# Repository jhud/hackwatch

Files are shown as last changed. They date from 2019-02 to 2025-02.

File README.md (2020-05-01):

# hackwatch
Want to run your Arduino code anywhere, any time? How about running a webserver from your wrist? This is a smartwatch running on the ESP32 + Arduino + 0.96' OLED (color or monochrome). Designed to run on cheap boards that have inbuilt LiPo battery circuitry and an OLED screen. It makes for quite a chunky watch, but the "always on" glow looks very cool, and a 500mAH battery currently lasts 10+ hours without any optimisation. The whole prototype was built for $12.

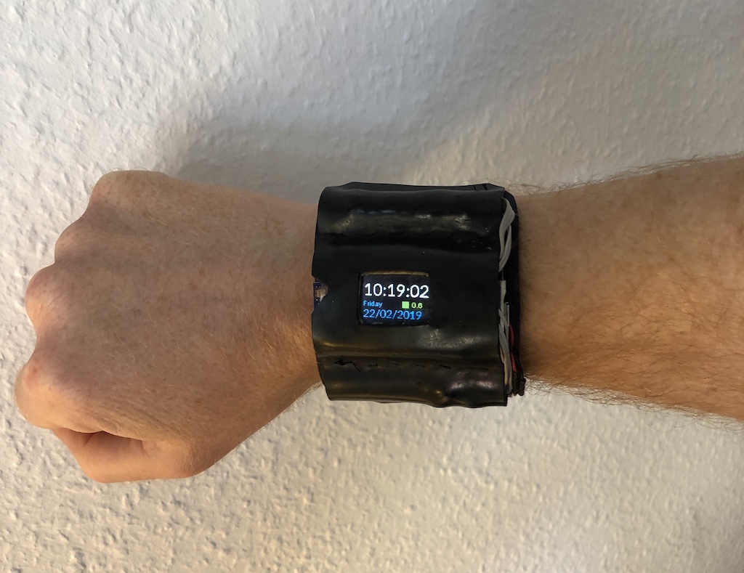
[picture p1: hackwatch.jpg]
Picture of hackwatch prototype Hackwatch prototype


Currently, the code uses your WiFi to sync with an NTP server, then show the time and date. I'll improve this project as I need features and find time.

The "flash" button on the GPIO0 of the development board is repurposed as a function button for the watch.

## Features
 - Flashlight, Stopwatch, Timer, Wifi Scan, UV Sensor with daily exposure graph
 - BLE connection with message notifications
 - Hardcoded calendar functionality, which will remind you when you need to catch buses, etc.
 - Screen off button, goes into sleep mode
 - Switch between color or B&W display on the application level, via a high-level UI interface.

# Setup

## Installation

Install the following dependencies:
 - Time (from Arduino library manager)
 - ```git clone https://github.com/mgo-tec/ESP32_SSD1331``` (for the color SSD1331 display)
 - ```git clone https://github.com/Smartphone-Companions/ESP32NotificationsLib.git``` (for the Bluetooth LE notifications)

You need to create a file called "secrets.h" which has your WiFi SSID and password:

const char ssid[] = "my access point";  //  your network SSID (name)
const char pass[] = "MyPassword12345";       // your network password

If you have an SSD1306 monochrome display, remove the #define COLOR_SCREEN. If you have an SSD1331 color display, set that define. Make sure you have the correct pins set in layout.cpp.

### OSX Troubleshooting

 - On OSX Catalina you might have trouble getting the "TTGO ESP32 OLED" board recognised by Arduino. If so, try installing the driver for the USB chip. https://www.silabs.com/products/development-tools/software/usb-to-uart-bridge-vcp-drivers

# Fabrication
The SVG file can be printed out, and the pieces cut from 1.5mm rubber. For attaching rubber, here are the methods tried (1 star fail, 5 star excellent):
 - Stitching with nylon thread *****
 - Double-sided tape ***
 - Vulcanising rubber cement **
 - Electrical tape **
 - Hot glue *
 The best method was to stick pieces with double-sided tape, and then stitch any load-bearing joins.

# Major tasks yet to do:
- Big refactor of messy prototype code
- Reduce power consumption (i.e. deep sleep when not changing display)
- Piezo chime or vibrate

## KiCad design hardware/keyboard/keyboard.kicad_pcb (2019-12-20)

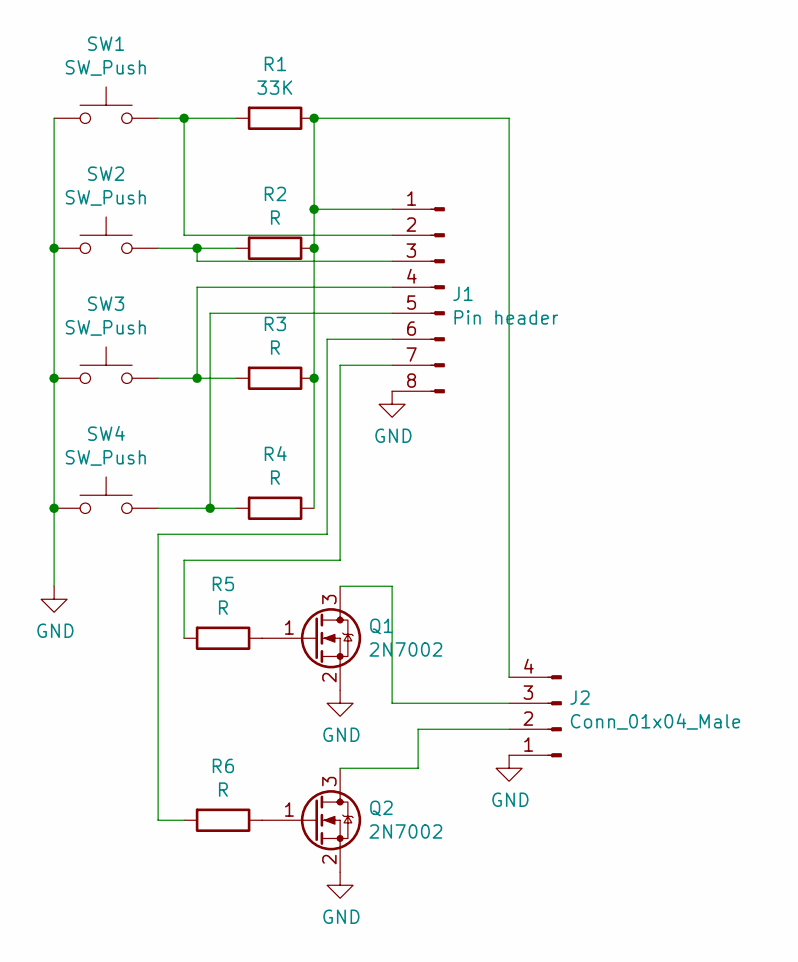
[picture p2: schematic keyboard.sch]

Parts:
J1: Pin header; PinHeader_2x04_P2.54mm_Vertical
J2: Conn_01x04_Male; PinHeader_1x04_P2.54mm_Vertical
Q1, Q2: 2N7002; SOT-23
R1: 33K; R_1206_3216Metric_Pad1.42x1.75mm_HandSolder
R2, R3, R4, R5, R6: R; R_1206_3216Metric_Pad1.42x1.75mm_HandSolder
SW1, SW2, SW3, SW4: SW_Push; SW_SPST_TL3342

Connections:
GND: J1.8, J2.1, Q1.2 (S), Q2.2 (S), SW1.1, SW2.1, SW3.1, SW4.1
unnamed: J1.1, J2.4, R1.1, R2.1, R3.1, R4.1
unnamed: J1.2, R1.2, SW1.2
unnamed: J1.3, R2.2, SW2.2
unnamed: J1.4, R3.2, SW3.2
unnamed: J1.5, R4.2, SW4.2
unnamed: J1.6, R6.2
unnamed: J1.7, R5.2
unnamed: J2.2, Q2.3 (D)
unnamed: J2.3, Q1.3 (D)
unnamed: Q1.1 (G), R5.1
unnamed: Q2.1 (G), R6.1

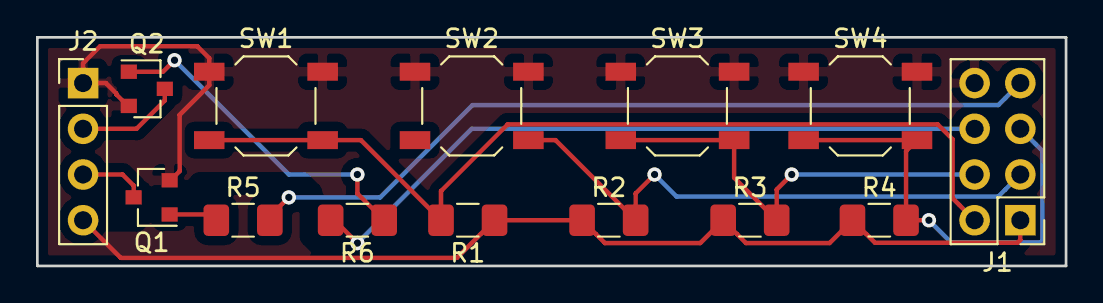
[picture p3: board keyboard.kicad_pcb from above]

Board: 2 copper layers, 57.1 x 12.7 mm, 14 parts (0 on the bottom side), 12 nets.

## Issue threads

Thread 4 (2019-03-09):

Hardware: designs for new keyboard boards

jhud, 2019-03-09:
The keyboards are probably the most clunky hardware part at the moment, and are just made out of through-hole veroboard. Do a proper kicad design. Also could add a space for LED/peripheral/buzzer/vibrator and mosfet.

jhud, 2019-12-20:
Done. Added the kicad files to the repo.

Closed 2019-12-20.

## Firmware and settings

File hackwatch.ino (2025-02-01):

// Smartwatch based on the ESP32 + SSD1306 OLED
// (c)2017 James Hudson, released under the GPL-3.0 license

// NTP based on https://www.arduino.cc/en/Tutorial/UdpNTPClient

// 55mA draw just showing time, changing every second

// Note on ESP32 sleep modes: the deep and light sleeps both work fine with the RTC,
// but on the "TTGO ESP32 OLED" board, the OLED screen blanks itself on sleep because of the reset pin
// configuration. This makes it not so useful for a watch, discounting any hardware mods to
// the board. So GPIO0 is used as an on/off switch.

 
#include <TimeLib.h> 
#include <WiFi.h>
#include <WiFiManager.h> // https://github.com/tzapu/WiFiManager

#include <WiFiUdp.h>

#include "util.h"
#include "states.h"
#include "layout.h"
#include "fonts.h"
#include "web.h"

#include "esp32notifications.h"

#include <esp_adc/adc_oneshot.h>

#define uS_TO_S_FACTOR 1000000  /* Conversion factor for micro seconds to seconds */

#define UV_SENSOR_ENABLE_GPIO 22

inline float mWcm2ToUVI(float mWcm2) { return mWcm2*3; }

static unsigned char uviBuffer[10*60*12];
static int bufferPos;

// NTP Servers:
IPAddress timeServer(216,239,35,8); // time.google.com

const int timeZone = 2; // Berlin winter is 1. Summer is 2

WiFiUDP Udp;


BLENotifications notifications;

static const int MENU_TIME_WIDTH = 30;
static const int STATUS_BAR_HEIGHT = 10;
static const int TIME_Y_POS = STATUS_BAR_HEIGHT; 
static const int timeHeight = 28;
static const int appointmentHeight = 28;
static const int APPOINTMENT_Y_POS = TIME_Y_POS+timeHeight-2;

unsigned long startTime = 0; 
time_t timer = 0;
int lastDay = -1;
int lastMinute = -1;

typedef struct CalendarEvent {
  char name[13];
  char day;
  short int minute;
  short int countdownMinutes;
};

// Sunday = 1
// Saturday = 7
CalendarEvent calendarEvents[] PROGMEM = {
  {"H'str U8", 1, 11*50, 20},
 /* {"Train OK", 3, 10*60, 30},
  {"Train OK", 4, 10*60, 30},
  {"Train OK", 5, 10*60, 30},*/
  {"H'str 277", 5, 20*60 + 5, 30},
};



int buttonPins[] = {32, 25, 26, 27, 35};
uint32_t inputMap;

State state = StateTime;

#define INTERUPT_PIN 0
void onboardButtonPressed() {

        detachInterrupt(INTERUPT_PIN);
        pinMode(INTERUPT_PIN, INPUT);
        Layout::enableDisplay(false);
  esp_sleep_enable_ext0_wakeup(GPIO_NUM_0,0);
    esp_deep_sleep_start();
}

void inputPressed0() { inputMap |=  1; }

void inputPressed1() { inputMap |=  2; }

void inputPressed2() { inputMap |=  4; }

void inputPressed3() { inputMap |=  8; }

void inputPressed4() { inputMap |=  16; }

bool isTimeSet() {
    time_t got_time = now();
 return (got_time > 1000);
}

const char btLogo[] PROGMEM = {0b1000100,0, 0b101000, 0, 0b11111111, 1,0b10101010,0,0b1000100,0};

void onBLEStateChanged(BLENotifications::State state) {
  uint16_t color = BLUE;
  switch (state) {
    case BLENotifications::StateConnected: color = GREEN; break;
    case BLENotifications::StateDisconnected:
      color = DARK_GRAY;

      /* We need to startAdvertising on disconnection, otherwise the ESP 32 will now be invisible.
      IMO it would make sense to put this in the library to happen automatically, but some people in the Espressif forums
      were requesting that they would like manual control over re-advertising.*/
      notifications.startAdvertising(); 
      
      break;
  }

  Layout::drawSprite1Bit(60, 1, 5, 9, btLogo, sizeof(btLogo), color);
}


// A notification arrived from the mobile device, ie a social media notification or incoming call.
void onNotificationArrived(const ArduinoNotification * notification, const Notification * rawNotification) {
    int textHeight = 11;

    String body(notification->message);
    //body.remove(20);

    Layout::drawStringInto(0, DISPLAY_HEIGHT-textHeight*2-2, DISPLAY_WIDTH, textHeight, notification->title, AlignLeft, LIGHT_BLUE);
    Layout::drawStringInto(0, DISPLAY_HEIGHT-textHeight-2, DISPLAY_WIDTH, textHeight, body, AlignLeft, LIGHT_BLUE);
}


void setup() 
{
  Serial.begin(115200);

  pinMode(UV_SENSOR_ENABLE_GPIO,OUTPUT);

  pinMode(34, INPUT);

  pinMode(16,OUTPUT);
  digitalWrite(16, LOW);    // set GPIO16 low to reset OLED
  delay(50); 
  digitalWrite(16, HIGH); // while OLED is running, must set GPIO16 in high

  pinMode(0, INPUT); // Let us use flash button on dev board as a function button

  for (int i=0; i<NUM_OF(buttonPins); i++) {
    pinMode(buttonPins[i], INPUT_PULLUP);  
  }

  Layout::init(false); // left handed

  memset(uviBuffer, 0, NUM_OF(uviBuffer));

  delay(50);
  if (isTimeSet()) {
    Serial.println("Woo! we woke up");
    timeval time_now; 
    gettimeofday(&time_now, NULL); 
    setTime(time_now.tv_sec); // @todo use a single system
  }
  else {
  
    WiFi.mode(WIFI_STA);

    WiFiManager wm;

    int i=0;
    while (!wm.autoConnect("Hackwatch")) {
      Layout::clear();
      Layout::drawStringInto(0, 0, DISPLAY_WIDTH, 18, "Connecting...", AlignLeft, GREEN);
      Layout::drawStringInto(0, 18, DISPLAY_WIDTH, 18, String(i), AlignLeft, WHITE);
      Layout::drawStringInto(0, 36, DISPLAY_WIDTH, 18, String(WiFi.status()), AlignLeft, GREEN);
      Layout::swapBuffers();

      i++;

      if (i==5) {
        Layout::clear();
        Layout::drawStringInto(0, 0, DISPLAY_WIDTH, 14, "Timed out. Sleeping.", AlignLeft, RED);  
        Layout::swapBuffers();
        WiFi.disconnect();
        WiFi.mode(WIFI_OFF);
        delay(500000);
        WiFi.mode(WIFI_STA);
        i=0;  
      }
      delay(10000);
    }

    Udp.begin(8888);

    Layout::clear();
    Layout::drawStringInto(0, 0, DISPLAY_WIDTH, DISPLAY_HEIGHT, "Getting time...");
    Layout::swapBuffers();

    auto ntpTime = getNtpTime();
    timeval time_now; 
    time_now.tv_sec = ntpTime;
    time_now.tv_usec = 0;

    settimeofday(&time_now, NULL); // as used by the onboard RTC which can survive deep sleeps
    setTime(ntpTime); // @todo use a single system
  }

  notifications.begin("Hackwatch");
    notifications.setConnectionStateChangedCallback(onBLEStateChanged);
    notifications.setNotificationCallback(onNotificationArrived);


 attachInterrupt(digitalPinToInterrupt(INTERUPT_PIN), onboardButtonPressed, RISING);


  attachInterrupt(digitalPinToInterrupt(buttonPins[0]), inputPressed0, FALLING);
  attachInterrupt(digitalPinToInterrupt(buttonPins[1]), inputPressed1, FALLING);
  attachInterrupt(digitalPinToInterrupt(buttonPins[2]), inputPressed2, FALLING);
  attachInterrupt(digitalPinToInterrupt(buttonPins[3]), inputPressed3, FALLING);
  attachInterrupt(digitalPinToInterrupt(buttonPins[4]), inputPressed4, FALLING);
}

void showMenu(const char * item1, const char * item2, const char * item3) {

      Layout::fillRect(0, 0, DISPLAY_WIDTH, 10, BLACK, BLACK);
      
      drawTimeInto(0,0,MENU_TIME_WIDTH, STATUS_BAR_HEIGHT, true, LIGHT_BLUE);

      Layout::drawStringInto(DISPLAY_WIDTH/3+ 4, 0, DISPLAY_WIDTH/3, STATUS_BAR_HEIGHT, item1, AlignCenter, LIGHT_BLUE);
       
      Layout::drawStringInto(DISPLAY_WIDTH*2/3, 0, DISPLAY_WIDTH/3, STATUS_BAR_HEIGHT, item2, AlignCenter, LIGHT_BLUE);
      Layout::drawStringInto(DISPLAY_WIDTH-22, 0, 22, STATUS_BAR_HEIGHT, item3, AlignRight, LIGHT_BLUE);


    Layout::drawLine(1, 0, 2, 0);
    Layout::drawLine(DISPLAY_WIDTH/3, 0, DISPLAY_WIDTH/3+2, 0);
    Layout::drawLine(DISPLAY_WIDTH*2/3, 0, DISPLAY_WIDTH*2/3+2, 0);
    Layout::drawLine(DISPLAY_WIDTH-2, 0, DISPLAY_WIDTH-1, 0);


}

void transitionState(State st) {
  switch (state) {
    case StateWifiScan:
      WiFi.disconnect();
      WiFi.mode(WIFI_OFF);
      break;
  }
  
  switch(st) {
    case StateTime:
      Layout::clear();
    showDate(0, 0, DISPLAY_WIDTH-2, 12); 
      break;

    case StateEnvironment:
    {
      Layout::setContrast(255);
      Layout::clear();

      drawUVGraph();

    }
      break;

    case StateMenu:
      Layout::setContrast(127);
      Layout::clear();
      showMenu(" PRV", "NXT", "OK");
      break;

    case StateStopwatch:
      startTime = millis();
      Layout::setContrast(127);
      Layout::clear();
      showMenu("", "RST", "LAP");
      break;

    case StateTimer:
      Layout::setContrast(127);
      Layout::clear();
      showMenu("+10", "+1", "GO");
      break;

    case StateFlashlight:
          Layout::setContrast(255);
          Layout::fillRect(0, 0, DISPLAY_WIDTH-1, DISPLAY_HEIGHT-1, WHITE, WHITE);
        Layout::swapBuffers();
      break;

     case StateWifiScan:
      WiFi.mode(WIFI_STA);
      WiFi.disconnect();
  }

  state = st;

}
 
void handleGlobalButtons() {
if (inputMap&1) {
    if (state == StateTime) {
      transitionState(StateMenu);
    }
    else {
       transitionState(StateTime);     
    }
    inputMap &= ~1;
}
}


void loop()
{  
  //Layout::clear();
 //       Layout::drawStringInto(0,0,DISPLAY_WIDTH,16,"| | . X O");   
//delay(10000);
//return;

  int hours = hour();
  const bool nighttime = (hours > 21) || (hours < 7);

  handleGlobalButtons();

  switch(state) {
    case StateTime:
      showTime(nighttime);  
      delay(1000);
      break;

    case StateEnvironment:
    {
      updateEnvironment(10);  
      delay(100);
      break;
    }

    case StateStopwatch:
    {
      updateStopwatch(11);
      break;
    }

    case StateMenu:
      updateMenu();
      delay(250);
      break;

    case StateTimer:
      updateTimer();
      delay(100);
      break;

    case StateFlashlight:
      delay(1000);
      break;

    case StateWifiScan:
      updateWifiScan(11, DISPLAY_HEIGHT-11);
      delay(5000);
      break;
  }

}

  static int menuSelected = 0;

struct MenuItem {
  char * name;
  State state;
};

MenuItem menuItems[] PROGMEM = {
  {"Environment", StateEnvironment},
  {"Stopwatch", StateStopwatch},
  //{"Flashlight", StateFlashlight},
  {"Timer", StateTimer},
  {"WiFi Scan", StateWifiScan}
};

void updateMenu() {

  if (inputMap == 0) {
    return;
  }

  if (inputMap&2) {  
      menuSelected+=NUM_OF(menuItems)-1;
      menuSelected %= NUM_OF(menuItems);

      Layout::fillRect(0, 24, DISPLAY_WIDTH, 12, BLACK, BLACK);
      
      inputMap &= ~2;
  }
  
  if (inputMap&4) {  
      menuSelected++;
      menuSelected %= NUM_OF(menuItems);
      
      Layout::fillRect(0, 24, DISPLAY_WIDTH, 12, BLACK, BLACK);
      
      inputMap &= ~4;
  }

  if (inputMap&8) {  
      transitionState(menuItems[menuSelected].state);
      inputMap &= ~8;
      return;
  }

  const int topBarHeight = 12;
  const int height = DISPLAY_HEIGHT - topBarHeight;
  const int selectedHeight = 30;
  const int unselectedHeight = (height-selectedHeight) / 2;
  
  
  Layout::drawStringInto(0,topBarHeight, DISPLAY_WIDTH, unselectedHeight, menuItems[(menuSelected+NUM_OF(menuItems)-1)%NUM_OF(menuItems)].name, AlignLeft, 0x9999);
  Layout::drawStringInto(0,topBarHeight+unselectedHeight, DISPLAY_WIDTH, selectedHeight, menuItems[menuSelected].name, AlignLeft);
  Layout::drawStringInto(0,topBarHeight+unselectedHeight+selectedHeight, DISPLAY_WIDTH, unselectedHeight, menuItems[(menuSelected+1)%NUM_OF(menuItems)].name, AlignLeft, 0x9999);
  Layout::swapBuffers();
}

void updateTimer() {
       char buffer[32];
      static int timerSeconds = 0;
      static bool running = false;

              drawTimeInto(0,0,MENU_TIME_WIDTH, 10, true, WHITE);

  if (inputMap&2) {  
      timerSeconds += 600;
      inputMap &= ~2;
            if (running == true) {
        timerSeconds = 0;
        running = false;
      }
       showMenu("+10", "+1", "GO");
  }

  if (inputMap&4) {  
      timerSeconds += 60;
      inputMap &= ~4;
            if (running == true) {
        timerSeconds = 0;
        running = false;
      }
      showMenu("+10", "+1", "GO");
  }

  
  if (inputMap&8) {  
          inputMap &= ~8;
      if (running == true) {
        timerSeconds = 0;
        running = false;
        return;
      }
      timer = now() + timerSeconds;
      running = true;
      timerSeconds = 0;
      showMenu("X", "X", "X");
  }
  
       if (running == true) {
      time_t currentSeconds = now();  
    time_t secondsRemaining = timer-currentSeconds;
    if (secondsRemaining >= 0) {
       Layout::drawDigitsInto(0,25,DISPLAY_WIDTH,DISPLAY_HEIGHT-25,secondsRemaining/60, secondsRemaining%60); 
    }
    else {
       Layout::drawStringInto(0,25,DISPLAY_WIDTH,32,"Done!"); 
    }
       }
       else {
        sprintf(buffer,"SET %02d min",timerSeconds/60); 
        Layout::drawStringInto(0,25,DISPLAY_WIDTH,DISPLAY_HEIGHT-25,buffer);    
       }

    Layout::swapBuffers();
}


void showDate(int x, int y, int w, int h) {
  char buffer[32];
  sprintf(buffer,"%s %02d/%02d", dayShortStr(weekday()), day(), month());
  Layout::drawStringInto(x, y, w, 10, buffer, AlignLeft, BLUE);
  }

void drawTimeInto(int x, int y, int w, int h, bool nighttime, Color color) {
       char buffer[32];
  int hours = hour();
if (!nighttime) {
   Layout::drawDigitsInto(x,y,w,h,hours, minute(), ':', second(), color);  
}
else {
    Layout::drawDigitsInto(x,y,w,h,hours, minute(), color);  
}
}

//The Arduino Map function but for floats
//From: http://forum.arduino.cc/index.php?topic=3922.0
float mapfloat(float x, float in_min, float in_max, float out_min, float out_max)
{
  return (x - in_min) * (out_max - out_min) / (in_max - in_min) + out_min;
}



int averageAnalogRead()
{
  byte numberOfReadings = 4;
  unsigned int runningValue = 0; 


   adc_oneshot_unit_handle_t adc1_handle;
    adc_oneshot_unit_init_cfg_t init_config1 = {
        .unit_id = ADC_UNIT_1,
    };
    ESP_ERROR_CHECK(adc_oneshot_new_unit(&init_config1, &adc1_handle));

    adc_oneshot_chan_cfg_t config = {
        .atten = ADC_ATTEN_DB_6, 
        .bitwidth = ADC_BITWIDTH_12,
    };
    ESP_ERROR_CHECK(adc_oneshot_config_channel(adc1_handle, ADC_CHANNEL_6, &config));



  for(int x = 0 ; x < numberOfReadings ; x++) {
    int adc_raw;
    ESP_ERROR_CHECK(adc_oneshot_read(adc1_handle, ADC_CHANNEL_6, &adc_raw));
    runningValue += adc_raw;
    runningValue /= numberOfReadings;
  }

    ESP_ERROR_CHECK(adc_oneshot_del_unit(adc1_handle));

  return(runningValue);  
}

float readUVSensor() {

  digitalWrite(UV_SENSOR_ENABLE_GPIO, HIGH);
  delay(1);
  

    float analog_value = averageAnalogRead();
  

  
  float uvIntensity = mapfloat(analog_value/2000.0f, 1.009, 2.9, 0.0, 15.0);

  /*Serial.print(" UV Intensity (mW/cm^2): ");
  Serial.print(uvIntensity);
  
  Serial.println();*/

        digitalWrite(UV_SENSOR_ENABLE_GPIO, LOW);


      inputMap &= ~2; // stop this triggering, ADC interferes with this GPIO for some reason

return uvIntensity;
}

Color colorForUVI(float uvi) {
  Color color;
        if (uvi < 3) {
        color = GREEN;
      }
      else if (uvi < 6) {
        color = YELLOW;
      }
      else if (uvi < 8) {
        color = ORANGE;
      }
      else if (uvi < 11) {
        color = RED;
      }
      else {
        color = VIOLET;
      }
      return color;
}

void updateUVIDisplay(float last_uv) {
      char buffer[32];

    int brightness = 255;
      Color color;

      float uvi = mWcm2ToUVI(last_uv); 

      // use UV to control global display dimming
      if (uvi < 0.2) {
        brightness = 0;
      }
      else if (uvi < 0.8) {
        brightness = (uvi-0.2)*600;
      }
      
      color = colorForUVI(uvi);
      sprintf(buffer,"%.01f", uvi); 

      Layout::drawStringInto(76, 0, DISPLAY_WIDTH-77, 12, buffer, AlignLeft, color);
      Layout::fillRect(71, 3, 3, STATUS_BAR_HEIGHT-4, color, color);

      Layout::setContrast(brightness);
}

void showTime(bool noSeconds){
    char buffer[32];

if (inputMap&16) {
      inputMap &= ~16;

  WiFi.mode(WIFI_STA);
    int status = WL_IDLE_STATUS; 
    int i=0;
    while (status != WL_CONNECTED) {
            Layout::fillRect(0, TIME_Y_POS, DISPLAY_WIDTH, timeHeight, BLACK, BLACK);
      Layout::drawStringInto(0, 18, DISPLAY_WIDTH, 18, "Toggling light...", AlignLeft, GREEN);
      Layout::swapBuffers();

      i++;

      if (i==5) {
        Layout::clear();
        Layout::drawStringInto(0, 18, DISPLAY_WIDTH, 14, "Timed out.", AlignLeft, RED);  
        Layout::swapBuffers();
        WiFi.disconnect();
        WiFi.mode(WIFI_OFF);
        return; 
      }
      delay(2000);
    }
      
  toggleRoomLights();

WiFi.disconnect();
WiFi.mode(WIFI_OFF);
      
 /*     transitionState(StateFlashlight);
      return;
      */
}

  if (inputMap&2) {  
      inputMap &= ~2;
    transitionState(menuItems[menuSelected].state);
    return;
  }

  

if (lastMinute == minute()) {
if (noSeconds) {
  return;
}

}

  lastMinute = minute();

    bool sensorUpdated = false;
    float last_uv = -1;
  if ((second()%6) == 0) {
    last_uv = readUVSensor();
    uviBuffer[bufferPos] = mWcm2ToUVI(last_uv*10);
    bufferPos++;
    bufferPos %= NUM_OF(uviBuffer);
    sensorUpdated = true;
  }
  
    if (day() != lastDay) {
     Layout::clear();
     showDate(0, 0, DISPLAY_WIDTH, 12); 
    lastDay = day(); 
    }

drawTimeInto(0, TIME_Y_POS, DISPLAY_WIDTH, timeHeight, noSeconds, WHITE);

for (int i=0; i<sizeof(calendarEvents) / sizeof(calendarEvents[0]); i++) {
  CalendarEvent event = calendarEvents[i];
  if (event.day == weekday()) {
    int currentSeconds = hour() * 3600 + minute()*60 + second();  
    int secondsRemaining = event.minute*60 - currentSeconds;
    if (secondsRemaining >= 0 && secondsRemaining <= event.countdownMinutes*60) {
          Layout::drawDigitsInto(0, APPOINTMENT_Y_POS, DISPLAY_WIDTH,appointmentHeight, secondsRemaining/60, secondsRemaining%60, RED);  
    Layout::drawStringInto(0, APPOINTMENT_Y_POS+appointmentHeight-2, 66, DISPLAY_HEIGHT-(timeHeight+appointmentHeight)+3, event.name, AlignRight, RED);

        const int top = APPOINTMENT_Y_POS+4;
        const int bot = APPOINTMENT_Y_POS+23;
        const int mid = (top+bot)/2;
    Layout::drawLine(72, top, 78, mid, RED);
    Layout::drawLine(72, bot, 78, mid, RED);
    Layout::drawLine(72, top, 72, bot, RED);
    sensorUpdated = false;
    }
    else if (secondsRemaining == -1) {
      Layout::clear();
      showDate(0, 0, DISPLAY_WIDTH, DISPLAY_HEIGHT-timeHeight); 
    }
  }
}
    if (sensorUpdated) {
      updateUVIDisplay(last_uv);
    }

  Layout::swapBuffers();
}

void updateEnvironment(int yOffset) {

  float last_uv = readUVSensor();

     char buffer[32];
     
  int y= yOffset;
  int h = 10;
  const int bucketSize = 20;
      sprintf(buffer,"UV: %.02f", last_uv); 
        Layout::drawStringInto(0, y, 50, h, buffer, AlignLeft, BLUE); y += h;

  Layout::scroll(1, yOffset, DISPLAY_WIDTH-1, DISPLAY_HEIGHT-1, 0, yOffset);
  static int anim;
    int start = (NUM_OF(uviBuffer)+bufferPos+anim) % NUM_OF(uviBuffer);
  int readFrom = start;
  anim+=bucketSize;

  Layout::drawLine(DISPLAY_WIDTH-1, yOffset, DISPLAY_WIDTH-1,  DISPLAY_HEIGHT - 1, BLACK);

  float uvi = 0;
  for (int j=0; j<bucketSize; j++) {
    readFrom %= NUM_OF(uviBuffer);
    auto val = uviBuffer[readFrom];

    if((readFrom%600) == 0) {
      Layout::drawLine(DISPLAY_WIDTH-1, yOffset, DISPLAY_WIDTH-1, DISPLAY_HEIGHT - 1, BLUE);  
      sprintf(buffer,"%d", (bufferPos-start)/600-1);  
      Layout::drawStringInto(DISPLAY_WIDTH-16, y, 10, h, buffer, AlignLeft, BLUE); y += h;   
    }
    
    readFrom++;
    uvi = _max(uvi, float(val));
  }

  y = DISPLAY_HEIGHT - uvi/2 - 1;
  Layout::drawLine(DISPLAY_WIDTH-1, y, DISPLAY_WIDTH-1, DISPLAY_HEIGHT - 1, colorForUVI(uvi/10));
  

  Layout::swapBuffers();
}

void drawUVGraph() {
  int pixelWidth = NUM_OF(uviBuffer)/DISPLAY_WIDTH;
  auto w = NUM_OF(uviBuffer)/pixelWidth;
int readFrom = NUM_OF(uviBuffer)+bufferPos;
for (int i=0; i< w; i++) {
  float uvi = 0;
  for (int j=0; j<pixelWidth; j++) {
    readFrom %= NUM_OF(uviBuffer);
    auto val = uviBuffer[readFrom];
    readFrom++;
    uvi = _max(uvi, float(val));
  }

  Layout::drawLine(i, DISPLAY_HEIGHT - uvi/2 - 1, i, DISPLAY_HEIGHT - 1, colorForUVI(uvi/10));
}
}

void updateStopwatch(int yOffset) {
    auto diff = millis() - startTime;
    auto sec = diff/1000;


   /* uviBuffer[bufferPos] = (millis()/1000) % 120;
    bufferPos++;
    bufferPos %= NUM_OF(uviBuffer);*/


     static auto lastTimePrint = 0;
     lastTimePrint += diff;
     if (lastTimePrint > 10000) {
      drawTimeInto(0,0,MENU_TIME_WIDTH, 11, true, WHITE); 
      lastTimePrint = 0;
     }

      Layout::drawDigitsInto(0,yOffset,DISPLAY_WIDTH,26,sec/60, sec%60, '.', ((diff/100)%10)*10);  
      Layout::swapBuffers();
      delay(100);

      if (inputMap&4) {
        startTime = millis();
            inputMap &= ~4;
      }

      if (inputMap&8) {
      Layout::drawDigitsInto(0, yOffset+26, DISPLAY_WIDTH,26, sec/60, sec%60, '.', ((diff/100)%10)*10);
            inputMap &= ~8;
      }
}



const int NTP_PACKET_SIZE = 48; // NTP time is in the first 48 bytes of message
byte packetBuffer[NTP_PACKET_SIZE]; //buffer to hold incoming & outgoing packets

time_t getNtpTime()
{
  while (Udp.parsePacket() > 0) ; // discard any previously received packets
  Serial.println("Transmit NTP Request");
  sendNTPpacket(timeServer);
  uint32_t beginWait = millis();
  while (millis() - beginWait < 1500) {
    int size = Udp.parsePacket();
    if (size >= NTP_PACKET_SIZE) {
      Serial.println(F("Receive NTP Response"));
      Udp.read(packetBuffer, NTP_PACKET_SIZE);  // read packet into the buffer
      unsigned long secsSince1900;
      // convert four bytes starting at location 40 to a long integer
      secsSince1900 =  (unsigned long)packetBuffer[40] << 24;
      secsSince1900 |= (unsigned long)packetBuffer[41] << 16;
      secsSince1900 |= (unsigned long)packetBuffer[42] << 8;
      secsSince1900 |= (unsigned long)packetBuffer[43];

WiFi.disconnect();
WiFi.mode(WIFI_OFF);
      
      return secsSince1900 - 2208988800UL + timeZone * SECS_PER_HOUR;
    }
  }
  Serial.println("No NTP Response :-(");
  return 0; // return 0 if unable to get the time
}
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

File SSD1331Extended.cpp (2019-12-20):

#include "SSD1331Extended.h"

SSD1331Extended::SSD1331Extended(uint8_t sck, uint8_t miso, uint8_t mosi, uint8_t cs, uint8_t dc, uint8_t rst) :
  ESP32_SSD1331(sck, miso, mosi, cs, dc, rst) {
  	
  }

void SSD1331Extended::drawStringInternal(int16_t xMove, int16_t yMove, char* text, uint16_t textLength, uint16_t textWidth, uint16_t color) {
  uint8_t textHeight       = pgm_read_byte(fontData + HEIGHT_POS);
  uint8_t firstChar        = pgm_read_byte(fontData + FIRST_CHAR_POS);
  uint16_t sizeOfJumpTable = pgm_read_byte(fontData + CHAR_NUM_POS)  * JUMPTABLE_BYTES;

  uint8_t cursorX         = 0;
  uint8_t cursorY         = 0;


  switch (textAlignment) {
    case TEXT_ALIGN_CENTER_BOTH:
      yMove -= textHeight >> 1;
    // Fallthrough
    case TEXT_ALIGN_CENTER:
      xMove -= textWidth >> 1; // divide by 2
      break;
    case TEXT_ALIGN_RIGHT:
      xMove -= textWidth;
      break;
  }

  // Don't draw anything if it is not on the screen.
  if (xMove + textWidth  < 0 || xMove > DISPLAY_WIDTH ) {return;}
  if (yMove + textHeight < 0 || yMove > DISPLAY_HEIGHT) {return;}

  for (uint16_t j = 0; j < textLength; j++) {
    int16_t xPos = xMove + cursorX;
    int16_t yPos = yMove + cursorY;

    byte code = text[j];
    if (code >= firstChar) {
      byte charCode = code - firstChar;

      // 4 Bytes per char code
      byte msbJumpToChar    = pgm_read_byte( fontData + JUMPTABLE_START + charCode * JUMPTABLE_BYTES );                  // MSB  \ JumpAddress
      byte lsbJumpToChar    = pgm_read_byte( fontData + JUMPTABLE_START + charCode * JUMPTABLE_BYTES + JUMPTABLE_LSB);   // LSB /
      byte charByteSize     = pgm_read_byte( fontData + JUMPTABLE_START + charCode * JUMPTABLE_BYTES + JUMPTABLE_SIZE);  // Size
      byte currentCharWidth = pgm_read_byte( fontData + JUMPTABLE_START + charCode * JUMPTABLE_BYTES + JUMPTABLE_WIDTH); // Width

      // Test if the char is drawable
      if (!(msbJumpToChar == 255 && lsbJumpToChar == 255)) {
        // Get the position of the char data
        uint16_t charDataPosition = JUMPTABLE_START + sizeOfJumpTable + ((msbJumpToChar << 8) + lsbJumpToChar);
        drawInternal(xPos, yPos, currentCharWidth, textHeight, fontData, charDataPosition, charByteSize, color);
      }

      cursorX += currentCharWidth;
    }
  }
}


void SSD1331Extended::drawString(int16_t xMove, int16_t yMove, String strUser, uint16_t color) {
  uint16_t lineHeight = pgm_read_byte(fontData + HEIGHT_POS);

  // char* text must be freed!
  char* text = utf8ascii(strUser);

  uint16_t yOffset = 0;
  // If the string should be centered vertically too
  // we need to now how heigh the string is.
  if (textAlignment == TEXT_ALIGN_CENTER_BOTH) {
    uint16_t lb = 0;
    // Find number of linebreaks in text
    for (uint16_t i=0;text[i] != 0; i++) {
      lb += (text[i] == 10);
    }
    // Calculate center
    yOffset = (lb * lineHeight) / 2;
  }

  uint16_t line = 0;
  char* textPart = strtok(text,"\n");
  while (textPart != NULL) {
    uint16_t length = strlen(textPart);
    drawStringInternal(xMove, yMove - yOffset + (line++) * lineHeight, textPart, length, getStringWidth(textPart, length), color);
    textPart = strtok(NULL, "\n");
  }
  free(text);
}

void SSD1331Extended::drawStringMaxWidth(int16_t xMove, int16_t yMove, uint16_t maxLineWidth, String strUser, uint16_t color) {
  uint16_t firstChar  = pgm_read_byte(fontData + FIRST_CHAR_POS);
  uint16_t lineHeight = pgm_read_byte(fontData + HEIGHT_POS);

  char* text = utf8ascii(strUser);

  uint16_t length = strlen(text);
  uint16_t lastDrawnPos = 0;
  uint16_t lineNumber = 0;
  uint16_t strWidth = 0;

  uint16_t preferredBreakpoint = 0;
  uint16_t widthAtBreakpoint = 0;

  for (uint16_t i = 0; i < length; i++) {
    strWidth += pgm_read_byte(fontData + JUMPTABLE_START + (text[i] - firstChar) * JUMPTABLE_BYTES + JUMPTABLE_WIDTH);

    // Always try to break on a space or dash
    if (text[i] == ' ' || text[i]== '-') {
      preferredBreakpoint = i;
      widthAtBreakpoint = strWidth;
    }

    if (strWidth >= maxLineWidth) {
      if (preferredBreakpoint == 0) {
        preferredBreakpoint = i;
        widthAtBreakpoint = strWidth;
      }
      drawStringInternal(xMove, yMove + (lineNumber++) * lineHeight , &text[lastDrawnPos], preferredBreakpoint - lastDrawnPos, widthAtBreakpoint, color);
      lastDrawnPos = preferredBreakpoint + 1;
      // It is possible that we did not draw all letters to i so we need
      // to account for the width of the chars from `i - preferredBreakpoint`
      // by calculating the width we did not draw yet.
      strWidth = strWidth - widthAtBreakpoint;
      preferredBreakpoint = 0;
    }
  }

  // Draw last part if needed
  if (lastDrawnPos < length) {
    drawStringInternal(xMove, yMove + lineNumber * lineHeight , &text[lastDrawnPos], length - lastDrawnPos, getStringWidth(&text[lastDrawnPos], length - lastDrawnPos), color);
  }

  free(text);
}

uint16_t SSD1331Extended::getStringWidth(const char* text, uint16_t length) {
  uint16_t firstChar        = pgm_read_byte(fontData + FIRST_CHAR_POS);

  uint16_t stringWidth = 0;
  uint16_t maxWidth = 0;

  while (length--) {
    stringWidth += pgm_read_byte(fontData + JUMPTABLE_START + (text[length] - firstChar) * JUMPTABLE_BYTES + JUMPTABLE_WIDTH);
    if (text[length] == 10) {
      maxWidth = max(maxWidth, stringWidth);
      stringWidth = 0;
    }
  }

  return max(maxWidth, stringWidth);
}

uint16_t SSD1331Extended::getStringWidth(String strUser) {
  char* text = utf8ascii(strUser);
  uint16_t length = strlen(text);
  uint16_t width = getStringWidth(text, length);
  free(text);
  return width;
}

void SSD1331Extended::setTextAlignment(OLEDDISPLAY_TEXT_ALIGNMENT textAlignment) {
  this->textAlignment = textAlignment;
}

void SSD1331Extended::setFont(const char *fontData) {
  this->fontData = fontData;
}

//#define DEBUG_DRAW
//void inline SSD1331Ex
void SSD1331Extended::drawInternal(int16_t xMove, int16_t yMove, int16_t width, int16_t height, const char *data, uint16_t offset, uint16_t bytesInData, uint16_t color) {

// Balance green
color = (color&(~63)) | (C_G(color)>>1);

#ifdef DEBUG_DRAW
  Serial.print("width ");
  Serial.println(width);
  Serial.print("height ");
  Serial.println(height);
  Serial.print("bytes ");
  Serial.println(bytesInData);
#endif
		
  const int skip = (8-(height))&7;

	uint8_t com[6];
	com[0] = 0x15; //Set Column Address
	com[3] = 0x75; //Set Row Address

  int i=0;
  for (int x= xMove; x< xMove+width; x++) {
  for (int y= yMove; y< yMove+height; y++) {

  	if ((i>>3)>=bytesInData) {
  		return;
  	}

    byte currentByte = pgm_read_byte(data + offset + (i>>3));



#ifdef DEBUG_DRAW
	Serial.print(col==0?"." : "*");
#endif



	char col = (currentByte >> (i&7))&1;
	if (col > 0) {


	      com[1] = x;
	      com[2] = x;

	      com[4] = y;
	      com[5] = y;

	    CommandWriteBytes(com, 6);
	    DataWriteBytes((uint8_t*)&color, 2);
	}
			i++;


  }
  i += skip;
}
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

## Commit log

2018-01-31 Multi wifi connection, timeout for network failures, calendar functions.
    [hackwatch.ino]
2018-02-02 Current consumption in standby is < 5mA
2018-02-20 Added stopwatch and button handling.
2018-04-01 Added uv sensor
2019-12-20 Uses BLENotifications library.
    [keyboard.kicad_pcb, keyboard.sch]
2019-12-20 Added ESP32NotificationsLib as a dependency

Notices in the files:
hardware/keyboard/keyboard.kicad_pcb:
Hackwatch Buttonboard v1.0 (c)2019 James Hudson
